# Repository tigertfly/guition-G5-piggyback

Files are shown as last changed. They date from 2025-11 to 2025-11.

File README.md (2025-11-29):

# Guition piggyback
Small add-on pcb that hooks to the SD card slot of Guition ESP32-S3-4848S040 development board to create a simulated standby flight instrument.

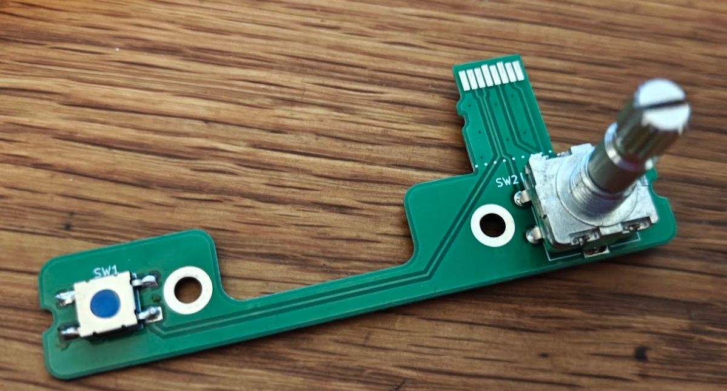
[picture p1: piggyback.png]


Inspired by [CC_G5 project by Chris Crawford](https://github.com/ccrawford/CC_G5), makes it possible to add an encoder and power button to the Guition development board without soldering.

## GPIO Pin Assignments 

The Guition development board uses four GPIO pins for the MicroSD card reader, that can be used for the simulated G5 functions.

| MobiFlight Device | GPIO |
|---|---|
| Power button | GPIO 42 |
| Encoder button | GPIO 47 |
| Encoder A Pin | GPIO 48 |
| Encoder B Pin | GPIO 41 |

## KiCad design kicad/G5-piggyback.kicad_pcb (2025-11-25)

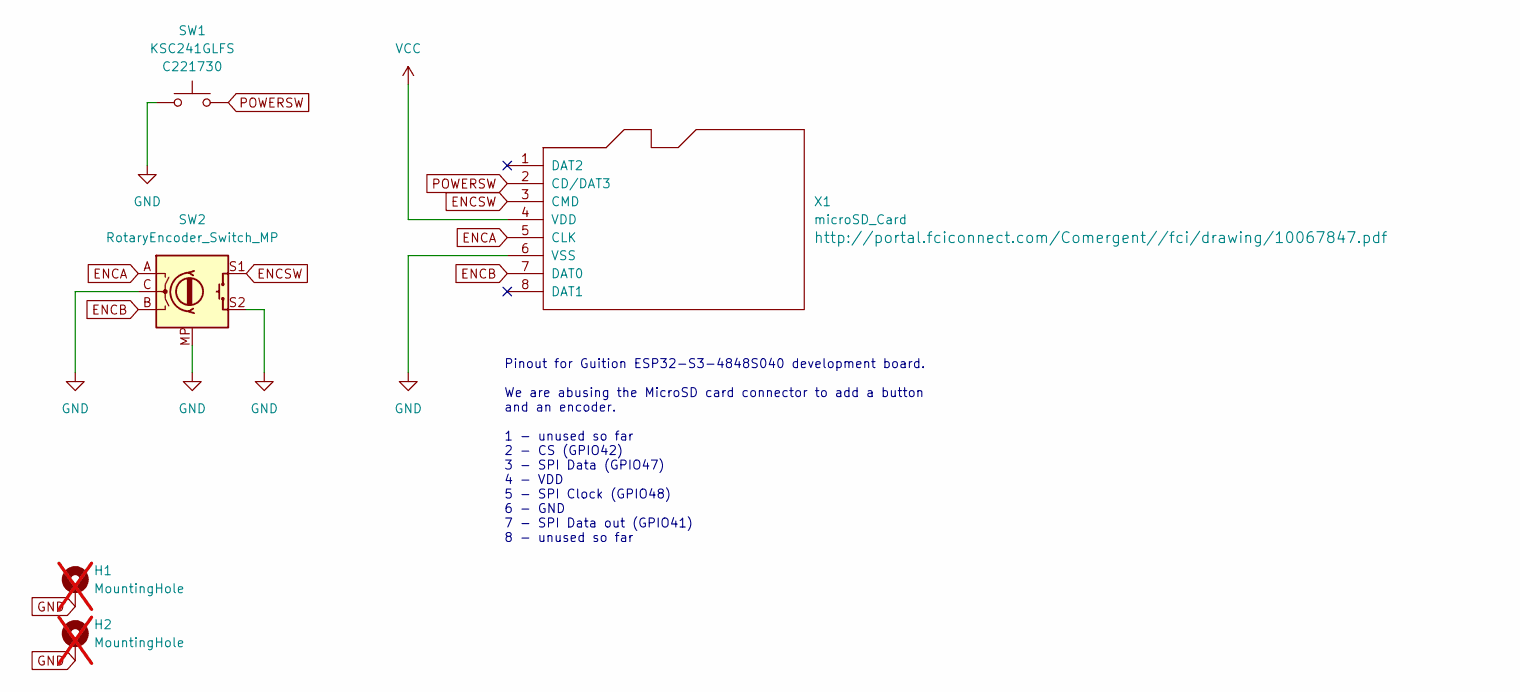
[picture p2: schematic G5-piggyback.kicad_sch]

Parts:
H1, H2: MountingHole; MountingHole_3.2mm_M3_ISO14580_Pad_TopBottom; not fitted
SW1: KSC241GLFS; LCSC Part # C221730
SW2: RotaryEncoder_Switch_MP; RotaryEncoder_Alps_EC11E-Switch_Vertical_H20mm_MountingHoles
X1: microSD_Card

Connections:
ENCA: SW2.A, X1.5 (CLK)
ENCB: SW2.B, X1.7 (DAT0)
ENCSW: SW2.S1, X1.3 (CMD)
GND: H1.1, H2.1, SW1.1, SW2.C, SW2.MP, SW2.S2, X1.6 (VSS)
POWERSW: SW1.2, X1.2 (CD/DAT3)
VCC: X1.4 (VDD)

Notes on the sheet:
Pinout for Guition ESP32-S3-4848S040 development board. We are abusing the MicroSD card connector to add a button and an encoder. 1 - unused so far 2 - CS (GPIO42) 3 - SPI Data (GPIO47) 4 - VDD 5 - SPI Clock (GPIO48) 6 - GND 7 - SPI Data out (GPIO41) 8 - unused so far

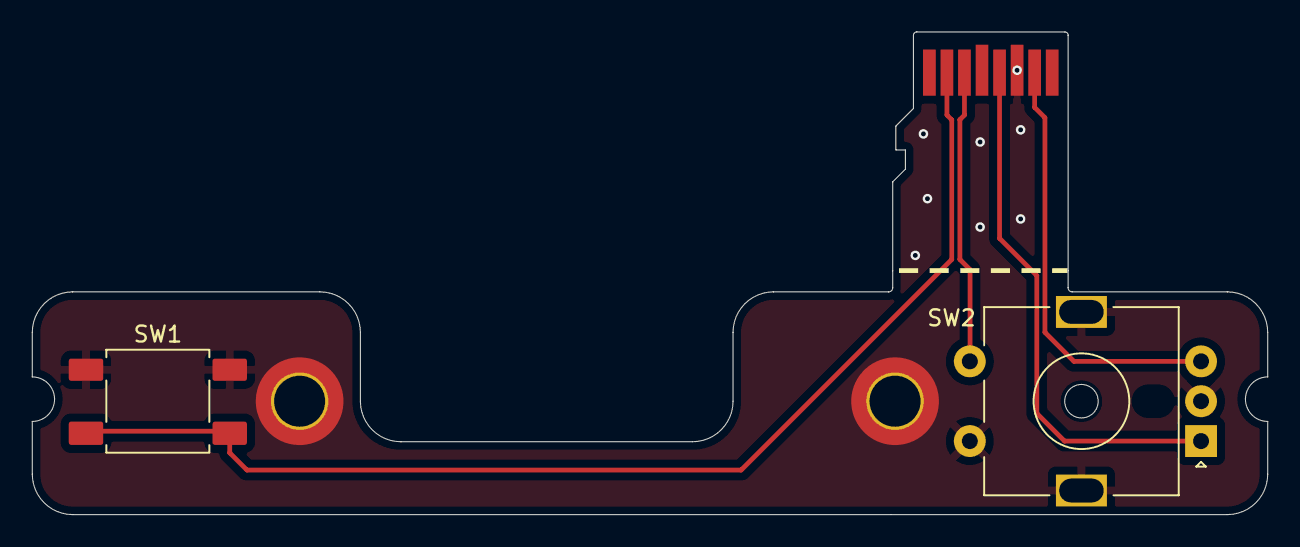
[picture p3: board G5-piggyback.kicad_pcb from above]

Board: 2 copper layers, 77.5 x 30.3 mm, 5 parts (0 on the bottom side), 5 nets.

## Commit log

2025-11-25 added photo of pcb
2025-11-25 pcb project added
    [G5-piggyback.kicad_pcb, G5-piggyback.kicad_sch]
2025-11-25 Updated layout slightly: centered things vertically, added slightly more space between devboard case and pcb top edge so the microsd click mechanism can hopefully operate without disassembly.
    [G5-piggyback.kicad_pcb, G5-piggyback.kicad_sch]

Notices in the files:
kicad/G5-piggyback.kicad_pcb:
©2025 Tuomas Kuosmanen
